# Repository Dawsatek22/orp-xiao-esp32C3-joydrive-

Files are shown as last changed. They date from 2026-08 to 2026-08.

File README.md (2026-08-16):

This is a repo for a 2wheeled dc motor robot with xiao esp32C3 board,Bluepad32 library,And a Bluetooth gamepad(currently a Xbox Wireless (model 1708, 2 buttons) controller).The It is recomended to read the eng_list.txt file first before anything else.The cad files are in the cad_parts folder and arduino code in the xioa_esp32c3_joydrive folder.The tutorial videos links are here(youtube versions release always 1 month later than other videos): vanillo.tv: https://vnlo.tv/EIX9zqSZXyI,Youtube link https://youtu.be/FFQTipYH78U.

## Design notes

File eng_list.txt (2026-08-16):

Playlist:
00:05 Warnings and summaries
00:09: Starting with building the
robot
13:08 upload and test the robot
15:51 showing results
16:00 goodbyes and recomendations

Summary and warnings:
The tutorial video instructions is explained in subtitles so be aware of that,This project uses 3 to 9v power so be careful,The cad parts used here in this project come from https://openroboticplatform.com/,Some stl file names are changed to make it easier to recognise,
The links for materials and tools are more for reference and not necessary the place to aquire them,
Be careful with the wiring so that it not can cause damage to the board or the breadbord power supply,
If there is any mistakes please comment back in the videos comment section so that i can fix it.
Recommended skills:
Programming arduino/esp32 boards in the arduino ide,Soldering,Using the Bluepad32 library,Working with 3 to 9v power,
3d printing or aquiring of nessacary cad parts.

Recommended software:
Arduino ide https://www.arduino.cc/en/software#ide,Bluepad32 library https://bluepad32.readthedocs.io/en/latest/,esp32 board library.
Tools and materials:

1x pc/laptop with access to arduino ide.
8x 20mm m/m dupont wires(possible 4 times  more to solder on the motors) https://www.tinytronics.nl/en/cables-and-connectors/cables-and-adapters/prototyping-wires/dupont-compatible-and-jumper/dupont-jumper-wire-male-male-20cm-10-wires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 .
1x Breadboard with 400 points https://www.tinytronics.nl/en/tools-and-mounting/prototyping-supplies/breadboards/breadboard-400-points .
2x tt dc motor with 2x 20mm m/m dupont wires soldered each side  https://www.tinytronics.nl/en/mechanics-and-actuators/motors/dc-motors/dc-transmission-motor-6v-200rpm-48:1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 .
1x 9v Battery Clip with DC Jack https://www.tinytronics.nl/en/power/battery-holders-and-clips/9v/9v-battery-clip-with-dc-jack
1x 9v battery https://www.amazon.nl/-/en/Kodak-CTA-30953437-Salina-battery/dp/B00ZA2UDKU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 .
2x rubber wheels for motors https://www.kiwi-electronics.com/en/wheel-65mm-rubber-tire-pair-3243?search=wheel.
 https://www.kiwi-electronics.com/en/breadboard-power-supply-3v3-5v-2946?search=breadbord%20power .
1x XIAO -ESP32-C3 with pins soldered https://www.tinytronics.nl/nl/development-boards/microcontroller-boards/met-wi-fi/seeed-studio-xiao-esp32-c3 .
1x gamepad compatible with Bluepad32 library (for this tutorial the: Xbox Wireless (model 1708, 2 buttons) is used) https://bluepad32.readthedocs.io/en/latest/supported_gamepads/ .
1x drv8833 motor driver with pins soldered https://www.tinytronics.nl/nl/mechanica-en-actuatoren/motoraansturingen-en-drivers/stappen-motoraansturingen-en-drivers/drv8833-bipolaire-stappenmotor-en-dc-motor-mo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 .
1x usb c data cable https://www.tinytronics.nl/nl/kabels-en-connectoren/kabels-en-adapters/usb/usb-c/goobay-59118-usb-c-usb-a-2.0-kabel-0.5m-3a-zwart .
1x m3 allen wrench.
For screws and nuts:
8x m3x12mm allen screws.
1x m3x16mm allen screws.
11x m3 nuts.

Cad parts(recommended for petg or pla filament):

1x nikodembartnik-3-plate_160mm.3mf
1x nikodembartnik-206-middle_breadboard_holder.stl
1x rupantar2002-147-MotorMountingBracket(left).stl
1x rupantar2002-148-MotorMountingBracket2(right).stl
1x Tenda-59-9V.3mf

Cad parts(recommended for tpu filament):
1x nikodembartnik-45-12mm_caster_wheel.3mf

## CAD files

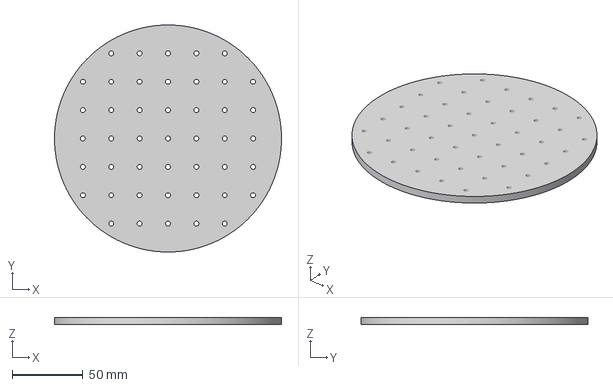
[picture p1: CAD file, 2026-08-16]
cad_parts/nikodembartnik-3-plate_160mm.3mf
160.0 x 160.0 x 5.00 mm

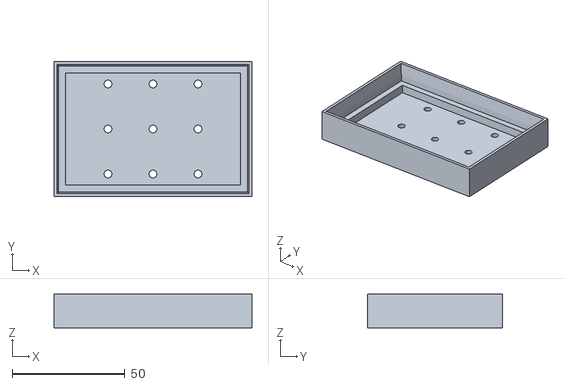
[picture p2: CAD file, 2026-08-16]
cad_parts/nikodembartnik-206-middle_breadboard_holder.stl
88.0 x 60.0 x 15.0

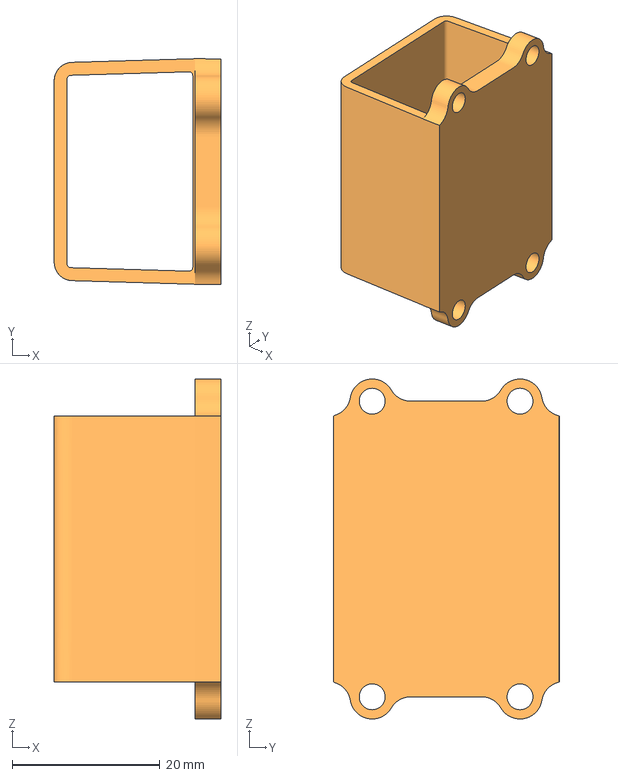
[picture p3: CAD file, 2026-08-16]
cad_parts/Tenda-59-9V.3mf
22.6 x 30.6 x 46.0 mm

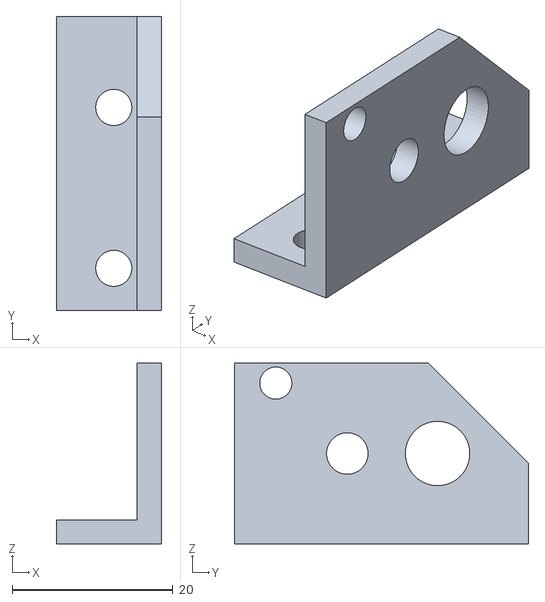
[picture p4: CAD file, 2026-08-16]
cad_parts/rupantar2002-148-MotorMountingBracket2(right).stl
13.0 x 36.6 x 22.5

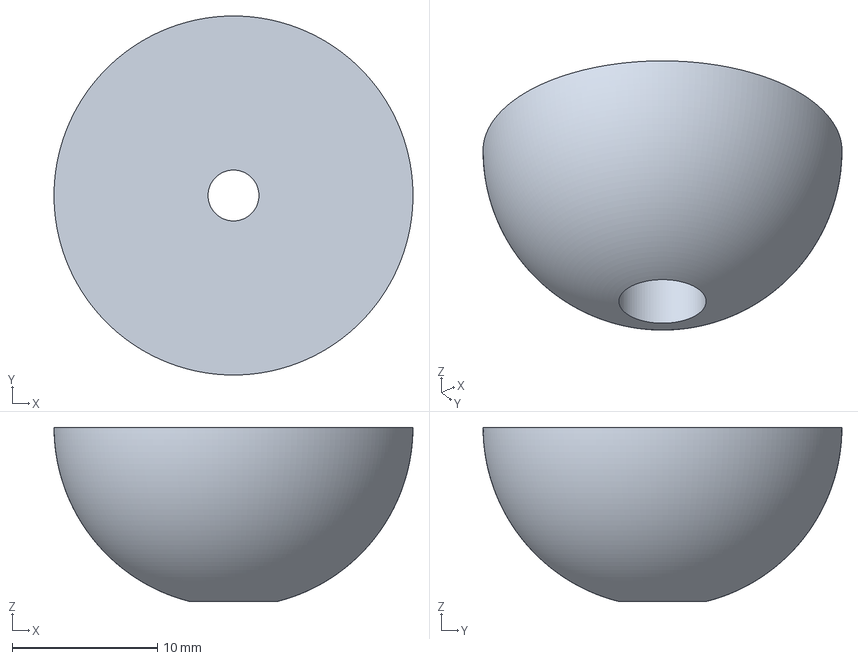
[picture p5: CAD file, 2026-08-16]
cad_parts/nikodembartnik-45-12mm_caster_wheel.3mf
24.7 x 24.7 x 12.0 mm

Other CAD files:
cad_parts/rupantar2002-147-MotorMountingBracket(left).stl

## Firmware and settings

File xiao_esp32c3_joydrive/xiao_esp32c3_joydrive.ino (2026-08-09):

#include <Bluepad32.h>

// This is a code example to drive a 2wheeled dc motor robot with esp32,Bluepad32 library,and a drv8833 motor driver,Bluetooth gamepad(currently a Xbox Wireless (model 1708, 2 buttons) controller).
// Link for the library is here : https://bluepad32.readthedocs.io/en/latest/
// link for the

int btn_A = 0x0001; // button a
int btn_B = 0x0002; // button b
int btn_X = 0x0000; // button x
int btn_Y = 0x0008; // button y
int btn_Lb = 0x0010; // Lb button
int btn_Rb = 0x0020; // RB button

// below are the motor driver pins number.
int in1 = 2;
int in2 = 3;
int in3 = 4;
int in4 = 5;
// below  are the functions for the motor directions
// If the robot follows the wrong directions.You can change the pin pwm values to fix it.

void forward() {

digitalWrite(in1,255);
digitalWrite(in2,0);
digitalWrite(in3,255);
digitalWrite(in4,0);
Serial.println("Motor goes forwards");

}

void backwards() {
digitalWrite(in1,0);
digitalWrite(in2,255);
digitalWrite(in3,0);
digitalWrite(in4,255);
Serial.println("motors goes backwards");

}

void left() {
digitalWrite(in1,0);
digitalWrite(in2,0);
digitalWrite(in3,0);
digitalWrite(in4,255);
Serial.println("motors goes left");

}


void right() {
digitalWrite(in1,0);
digitalWrite(in2,255);
digitalWrite(in3,0);
digitalWrite(in4,0);
Serial.println("motors goes right");

}

void stop() {

digitalWrite(in1,0);
digitalWrite(in2,0);
digitalWrite(in3,0);
digitalWrite(in4,0);
Serial.println("Motors stops");

}
ControllerPtr myControllers[BP32_MAX_GAMEPADS];

// This callback gets called any time a new gamepad is connected.
// Up to 4 gamepads can be connected at the same time.
void onConnectedController(ControllerPtr ctl) {
    bool foundEmptySlot = false;
    for (int i = 0; i < BP32_MAX_GAMEPADS; i++) {
        if (myControllers[i] == nullptr) {
            Serial.printf("CALLBACK: Controller is connected, index=%d\n", i);
            // Additionally, you can get certain gamepad properties like:
            // Model, VID, PID, BTAddr, flags, etc.
            ControllerProperties properties = ctl->getProperties();
            Serial.printf("Controller model: %s, VID=0x%04x, PID=0x%04x\n", ctl->getModelName().c_str(), properties.vendor_id,
                           properties.product_id);
            myControllers[i] = ctl;
            foundEmptySlot = true;
            break;
        }
    }
    if (!foundEmptySlot) {
        Serial.println("CALLBACK: Controller connected, but could not found empty slot");
    }
}

void onDisconnectedController(ControllerPtr ctl) {
    bool foundController = false;

    for (int i = 0; i < BP32_MAX_GAMEPADS; i++) {
        if (myControllers[i] == ctl) {
            Serial.printf("CALLBACK: Controller disconnected from index=%d\n", i);
            myControllers[i] = nullptr;
            foundController = true;
            break;
        }
    }

    if (!foundController) {
        Serial.println("CALLBACK: Controller disconnected, but not found in myControllers");
    }
}

void dumpGamepad(ControllerPtr ctl) {
    Serial.printf(
        "idx=%d, dpad: 0x%02x, buttons: 0x%04x, axis L: %4d, %4d, axis R: %4d, %4d, brake: %4d, throttle: %4d, "
        "misc: 0x%02x, gyro x:%6d y:%6d z:%6d, accel x:%6d y:%6d z:%6d\n",
        ctl->index(),        // Controller Index
        ctl->dpad(),         // D-pad
        ctl->buttons(),      // bitmask of pressed buttons
        ctl->axisX(),        // (-511 - 512) left X Axis
        ctl->axisY(),        // (-511 - 512) left Y axis
        ctl->axisRX(),       // (-511 - 512) right X axis
        ctl->axisRY(),       // (-511 - 512) right Y axis
        ctl->brake(),        // (0 - 1023): brake button
        ctl->throttle(),     // (0 - 1023): throttle (AKA gas) button
        ctl->miscButtons(),  // bitmask of pressed "misc" buttons
        ctl->gyroX(),        // Gyro X
        ctl->gyroY(),        // Gyro Y
        ctl->gyroZ(),        // Gyro Z
        ctl->accelX(),       // Accelerometer X
        ctl->accelY(),       // Accelerometer Y
        ctl->accelZ()        // Accelerometer Z
    );
}



void processGamepad(ControllerPtr ctl) {
    // There are different ways to query whether a button is pressed.
    // By query each button individually:
    //  a(), b(), x(), y(), l1(), etc...
    // butt currently this function is used to control motor direction
    if (ctl->buttons() == btn_Y){
     
     forward();
     
    }
 if (ctl->buttons() == btn_A) {
     
     backwards();
        }
 
  if (ctl->buttons() == btn_X) {
     
     stop();
        }


        if (ctl->buttons() == btn_Lb) {
     
     left();
        }


        if (ctl->buttons() == btn_Rb) {
     
     right();
        }

    // Another way to query controller data is by getting the buttons() function.
    // See how the different "dump*" functions dump the Controller info.
    dumpGamepad(ctl);
}


void processControllers() {
    for (auto myController : myControllers) {
        if (myController && myController->isConnected() && myController->hasData()) {
            if (myController->isGamepad()) {
                processGamepad(myController);
           
            } else {
                Serial.println("Unsupported controller");
            }
        }
    }
}

// Arduino setup function. Runs in CPU 1
void setup() {
    pinMode(in1,OUTPUT);
    pinMode(in2,OUTPUT);
    pinMode(in3,OUTPUT);
    pinMode(in4,OUTPUT);
    Serial.begin(115200);
    Serial.printf("Firmware: %s\n", BP32.firmwareVersion());
    const uint8_t* addr = BP32.localBdAddress();
    Serial.printf("BD Addr: %2X:%2X:%2X:%2X:%2X:%2X\n", addr[0], addr[1], addr[2], addr[3], addr[4], addr[5]);

    // Setup the Bluepad32 callbacks
    BP32.setup(&onConnectedController, &onDisconnectedController);

    // "forgetBluetoothKeys()" should be called when the user performs
    // a "device factory reset", or similar.
    // Calling "forgetBluetoothKeys" in setup() just as an example.
    // Forgetting Bluetooth keys prevents "paired" gamepads to reconnect.
    // But it might also fix some connection / re-connection issues.
    BP32.forgetBluetoothKeys();

    // Enables mouse / touchpad support for gamepads that support them.
    // When enabled, controllers like DualSense and DualShock4 generate two connected devices:
    // - First one: the gamepad
    // - Second one, which is a "virtual device", is a mouse.
    // By default, it is disabled.
    BP32.enableVirtualDevice(false);
}

// Arduino loop function. Runs in CPU 1.
void loop() {
    // This call fetches all the controllers' data.
    // Call this function in your main loop.
    bool dataUpdated = BP32.update();
    if (dataUpdated)
        processControllers();

    // The main loop must have some kind of "yield to lower priority task" event.
    // Otherwise, the watchdog will get triggered.
    // If your main loop doesn't have one, just add a simple `vTaskDelay(1)`.
    // Detailed info here:
    // https://stackoverflow.com/questions/66278271/task-watchdog-got-triggered-the-tasks-did-not-reset-the-watchdog-in-time

    //     vTaskDelay(1);
    delay(150);
}

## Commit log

2026-08-09 Initialize README with preview over view
    Added project description for a 2-wheeled DC motor robot.
2026-08-16 Update README with CAD files and Arduino code details
    Added information about CAD files and Arduino code locations.
